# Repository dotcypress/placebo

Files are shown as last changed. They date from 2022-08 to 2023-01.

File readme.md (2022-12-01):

# Placebo

Truly minimal STM32G0/STM32C0 proto board.

## Features

* Breadboard/Perfboard friendly
* Power line bypass capacitors
* Reset circuit
* [`Tag-Connect TC2030-CTX-NL`](https://www.tag-connect.com/product/tc2030-ctx-nl-stdc14-for-use-with-stm32-processors-with-stlink-v3) programming connector
* Optional battery connector with LDO
* Optional configurable LED

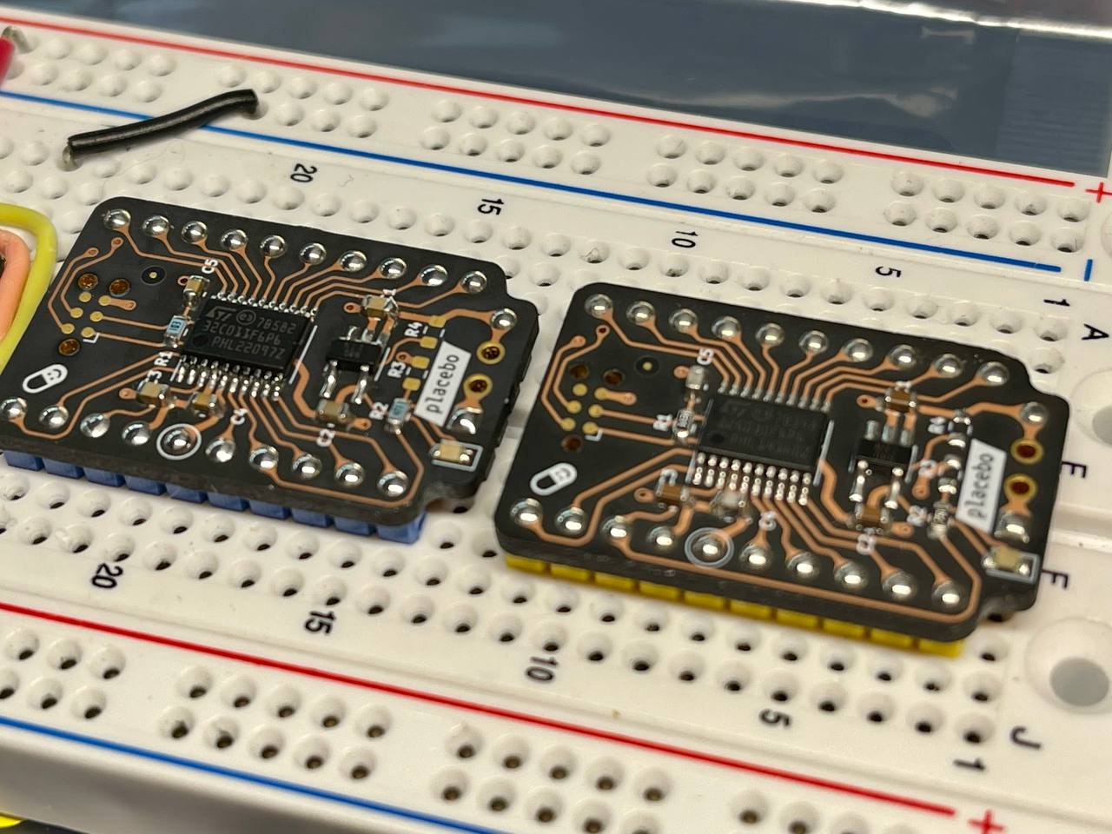
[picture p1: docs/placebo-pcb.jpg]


## Pinout

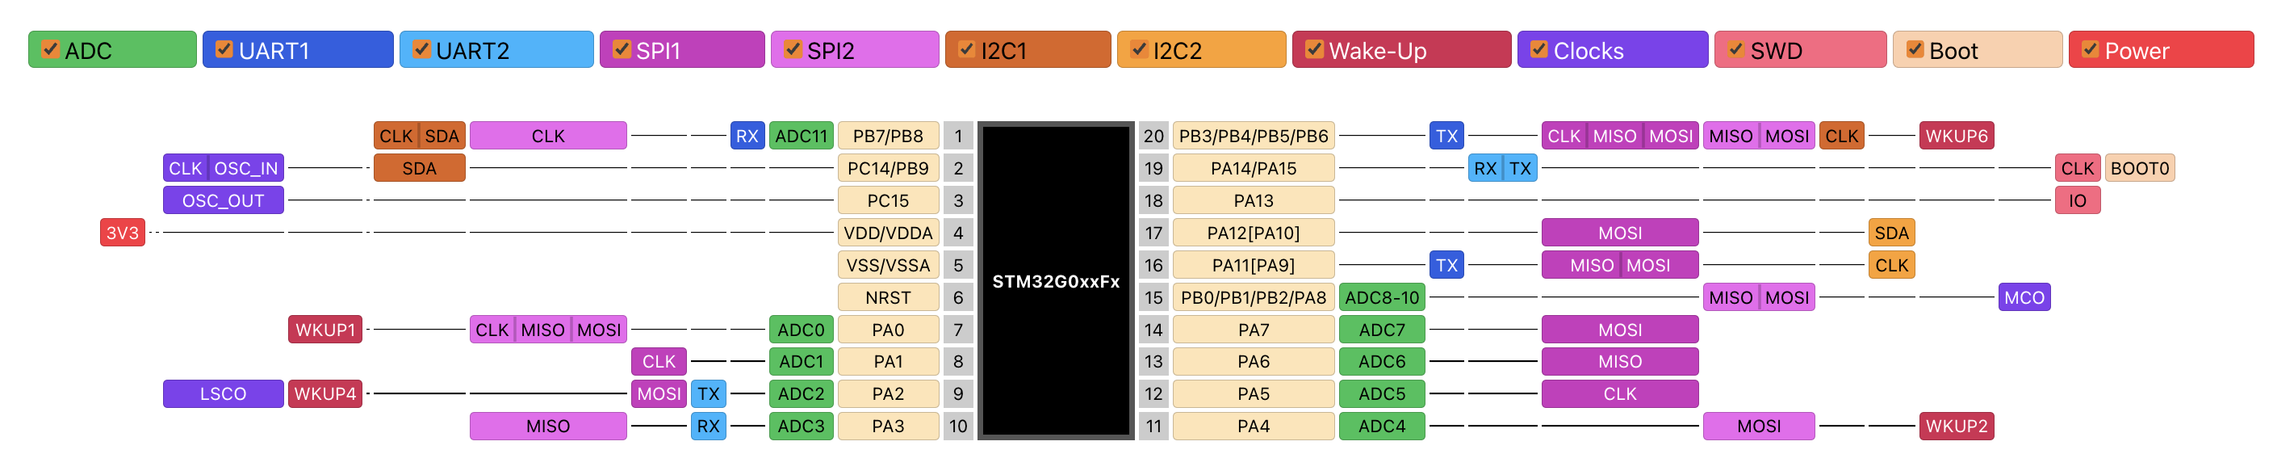
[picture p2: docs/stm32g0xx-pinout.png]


## Rust firmware

1. Install rustup by following the instructions at https://rustup.rs
2. Install Cortex-M0, M0+, and M1 (ARMv6-M architecture) target: `rustup target add thumbv6m-none-eabi`
3. Install LLVM tools: `rustup component add llvm-tools-preview`
4. Install cargo-binutils: `cargo install cargo-binutils` (Note: on some Linux distros (e.g. Ubuntu) you may need to install the packages build-essential, gcc-arm-none-eabi, libssl-dev and pkg-config prior to installing cargo-binutils.)
5. Install cargo-generate: `cargo install cargo-generate`
6. Generate project: `cargo generate --git https://github.com/dotcypress/placebo-template.git`
7. Build firmware: `cargo build --release`
8. Flash microcontroller: `cargo run --release`

## Resources

- [Order PCB on Oshpark](https://oshpark.com/shared_projects/tT7z3ldx)
- [Schematics](docs/placebo.pdf)
- [Gerber files](docs/placebo.zip)
- [BOM](docs/placebo.csv)
- [Interactive BOM](https://htmlpreview.github.io/?https://github.com/dotcypress/placebo/blob/main/docs/ibom.html)

## License

Licensed under either of

- Apache License, Version 2.0 ([LICENSE-APACHE](LICENSE-APACHE) or
  http://www.apache.org/licenses/LICENSE-2.0)
- MIT license ([LICENSE-MIT](LICENSE-MIT) or http://opensource.org/licenses/MIT)

at your option.

### Contribution

Unless you explicitly state otherwise, any contribution intentionally submitted
for inclusion in the work by you, as defined in the Apache-2.0 license, shall be
dual licensed as above, without any additional terms or conditions.

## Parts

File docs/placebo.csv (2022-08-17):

Designator | Comment | Footprint | Mouser Link
U1 | AP7370-33W5 | SOT-23-5 | https://www.mouser.com/c/?q=AP7370-33W5-7
U2 | STM32G030F6P6TR | TSSOP-20 | https://www.mouser.com/c/?q=STM32G030F6P6TR
D1 | LED | 0603 | https://www.mouser.com/c/?q=SML-D12W8WT86A
R1 | 10K | 0603 | https://www.mouser.com/c/?q=CRT0603-FZ-1002ELF
R2, R4 | 330R | 0603 | https://www.mouser.com/c/?q=CRT0603-FY-3300ELF
C3, C5 | 100nF | 0603 | https://www.mouser.com/c/?q=C0603C104J4RAC
C1, C2, C4 | 10uF | 0603 | https://www.mouser.com/c/?q=CL10A106MA8NRNC

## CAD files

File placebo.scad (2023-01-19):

module PlaceboCutout(height=1.6) {
  translate([-10.76, -16.6, -height/2])
    hull()
    linear_extrude(height=height, convexity=8)
    import(file="placebo.svg");
}

module PlaceboPCB(pin_height=10, pin_offset=2) {
  PlaceboCutout();

  translate([-0.1, 1.1, 0])
    cube([18.4, 26, 1.6], center=true);
  translate([-0.1, -12.4, 0])
    cube([14, 4, 1.6], center=true);

  for (i=[0:9]) {
    rotate([0, 0, 90]) {
      translate([i*2.54 - 10.2, 7.8, -pin_offset])
        cylinder(d=1.4, h=pin_height, center=true);
      translate([i*2.54 - 10.2, -7.5, -pin_offset])
        cylinder(d=1.4, h=pin_height, center=true);
    }
  }

  for (i=[-1:2]) {
    translate([i*2.54, -12.6, -pin_offset])
      cylinder(d=1.4, h=pin_height, center=true);
  }

  *translate([0, 11.8, 0.6])
    cube([7, 4, 0.6], center=true);
}

module Printer(d=7) {
  cr=3;
  h=3;
  w=64;
  l=50;

  difference() {
    union() {
      hull() {
        translate([w/2-cr,d,0]) cylinder(r=cr, h=h, center=true);
        translate([w/2-cr,l/2-cr,0]) cylinder(r=cr, h=h, center=true);
        translate([-w/2+cr,l/2-cr,0]) cylinder(r=cr, h=h, center=true);
        translate([-w/2+cr,0,0]) cylinder(r=cr, h=h, center=true);
      }
      hull() {
        translate([w/2-cr,-l/2+cr,0]) cylinder(r=cr, h=h, center=true);
        translate([w/2-cr,-d,0]) cylinder(r=cr, h=h, center=true);
        translate([-w/2+cr,0,0]) cylinder(r=cr, h=h, center=true);
        translate([-w/2+cr,-l/2+cr,0]) cylinder(r=cr, h=h, center=true);
      }
    }
    rotate([0,0,90])
      translate([0,-3,h/2-0.79])
      PlaceboCutout();
    rotate([0,0,90])
      translate([0,-3,h/2-0.79])
      scale([0.85,0.9,10]) 
      PlaceboCutout();
  }
}

$fn=128;

// projection(cut=true) translate([0,0,1])
Printer();

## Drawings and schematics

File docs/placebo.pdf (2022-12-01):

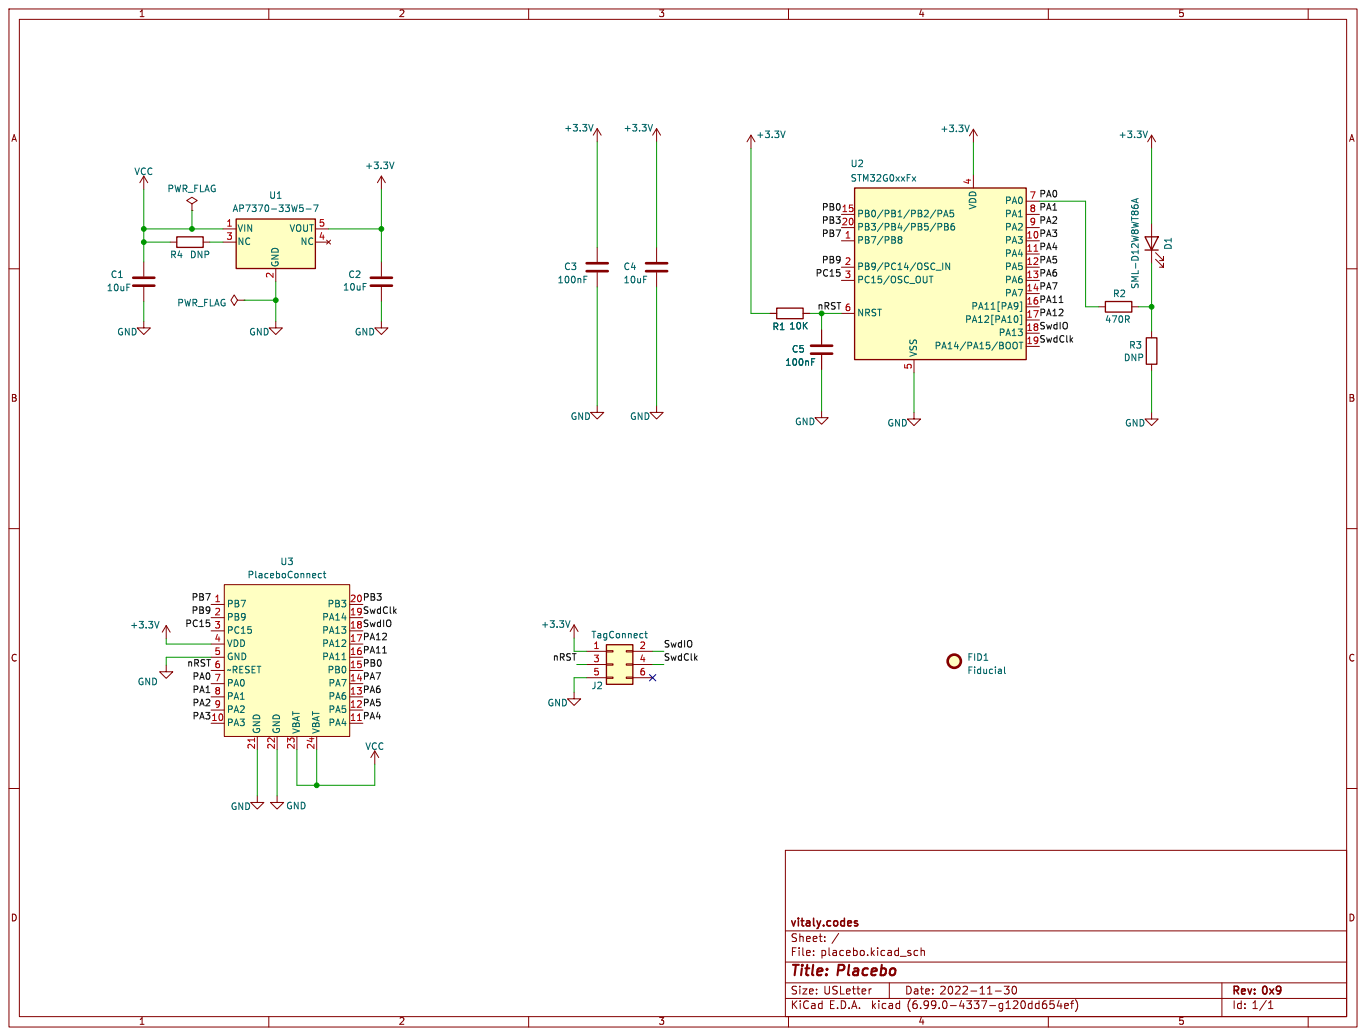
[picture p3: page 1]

2 NC 3 NC 4 VOUT 5 U1 AP7370-33W5-7 GND

File: placebo.kicad_sch Sheet: / vitaly.codes

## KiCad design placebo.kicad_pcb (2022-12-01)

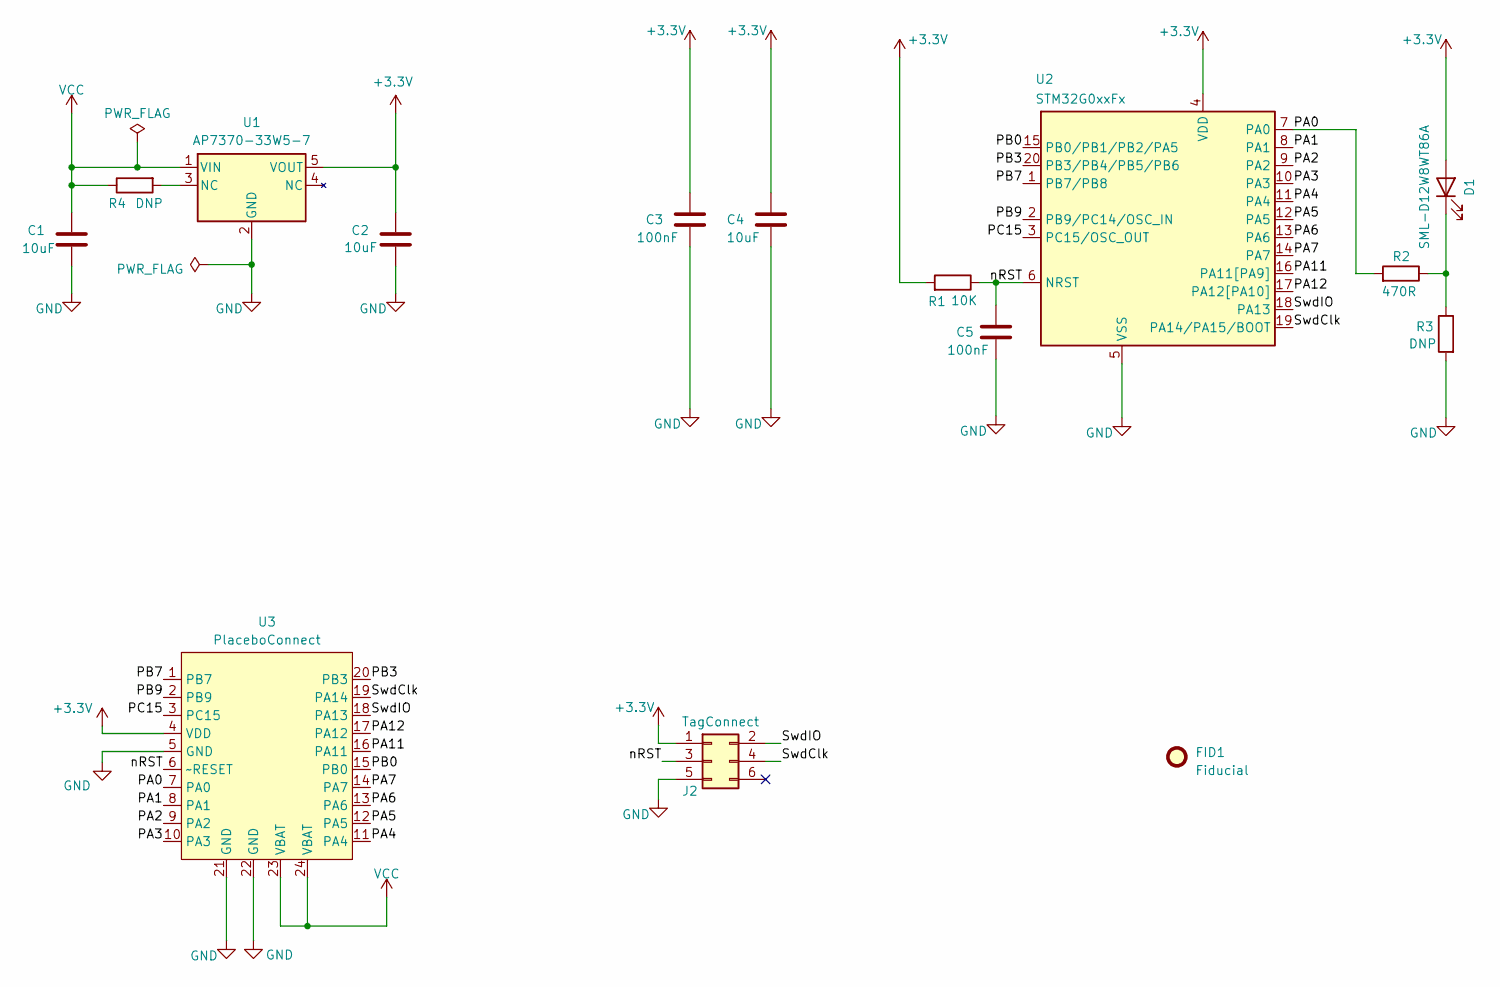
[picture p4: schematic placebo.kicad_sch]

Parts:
C1, C2, C4: 10uF; C_0603_1608Metric
C3, C5: 100nF; C_0603_1608Metric
D1: SML-D12W8WT86A; LED_0603_1608Metric
FID1: Fiducial; Fiducial_0.5mm_Mask1.5mm
J2: TagConnect; Tag-Connect_TC2030-IDC-NL_2x03_P1.27mm_Vertical
R1: 10K; R_0603_1608Metric
R2: 470R; R_0603_1608Metric
R3, R4: DNP; R_0603_1608Metric
U1: AP7370-33W5-7; TSOT-23-5_HandSoldering
U2: STM32G0xxFx; TSSOP-20_4.4x6.5mm_P0.65mm
U3: PlaceboConnect; PlaceboConnect_Cutout

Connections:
+3V3: C2.1, C3.1, C4.1, D1.2 (A), J2.1, R1.2, U1.5 (VOUT), U2.4 (VDD), U3.4 (VDD)
/PA0: R2.2, U2.7 (PA0), U3.7 (PA0)
/PA1: U2.8 (PA1), U3.8 (PA1)
/PA2: U2.9 (PA2), U3.9 (PA2)
/PA3: U2.10 (PA3), U3.10 (PA3)
/PA4: U2.11 (PA4), U3.11 (PA4)
/PA5: U2.12 (PA5), U3.12 (PA5)
/PA6: U2.13 (PA6), U3.13 (PA6)
/PA7: U2.14 (PA7), U3.14 (PA7)
/PA11: U2.16 (PA11[PA9]), U3.16 (PA11)
/PA12: U2.17 (PA12[PA10]), U3.17 (PA12)
/PB0: U2.15 (PB0/PB1/PB2/PA5), U3.15 (PB0)
/PB3: U2.20 (PB3/PB4/PB5/PB6), U3.20 (PB3)
/PB7: U2.1 (PB7/PB8), U3.1 (PB7)
/PB9: U2.2 (PB9/PC14/OSC_IN), U3.2 (PB9)
/PC15: U2.3 (PC15/OSC_OUT), U3.3 (PC15)
/SwdClk: J2.4, U2.19 (PA14/PA15/BOOT), U3.19 (PA14)
/SwdIO: J2.2, U2.18 (PA13), U3.18 (PA13)
/nRST: C5.1, J2.3, R1.1, U2.6 (NRST), U3.6 (~RESET)
GND: C1.2, C2.2, C3.2, C4.2, C5.2, J2.5, R3.2, U1.2 (GND), U2.5 (VSS), U3.5 (GND), U3.21 (GND), U3.22 (GND)
unnamed: D1.1 (K), R2.1, R3.1
unnamed: R4.2, U1.3 (NC)
VCC: C1.1, R4.1, U1.1 (VIN), U3.23 (VBAT), U3.24 (VBAT)

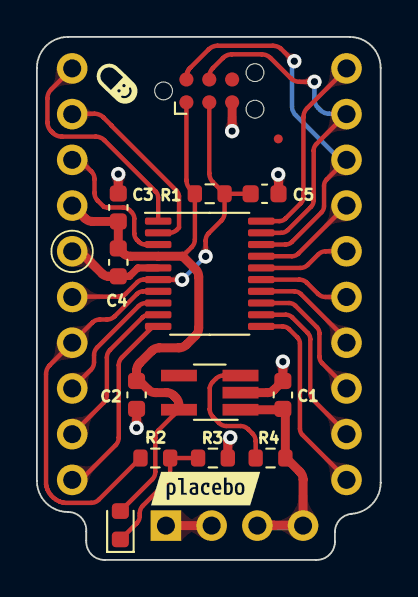
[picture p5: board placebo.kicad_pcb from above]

Board: 2 copper layers, 19.1 x 29.1 mm, 17 parts (0 on the bottom side), 23 nets.

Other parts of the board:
LOGO1: LOGO
kibuzzard-631021FD: G***; kibuzzard-631021FD

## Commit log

2021-07-22 rev 1
    [placebo.csv, placebo.kicad_pcb, placebo.kicad_sch]
2021-07-23 update docs
    [placebo.kicad_pcb]
2021-08-26 rev 2
    [placebo.kicad_pcb]
2021-12-26 rev 0x3
    [placebo.kicad_pcb, placebo.kicad_sch]
2022-07-19 rev 0x4
    [placebo.kicad_pcb, placebo.kicad_sch]
2022-08-14 rev. 0x6
    [placebo.csv, placebo.kicad_pcb, placebo.kicad_sch]
2022-08-19 add cad files
    [placebo.kicad_pcb, placebo.scad]
2022-09-04 rev. 0x8
    [placebo.kicad_pcb, placebo.kicad_sch, placebo.scad]
2022-09-17 panel rev. 0x8
    [placebo.kicad_pcb]
2022-09-17 update BOM
    [placebo.kicad_pcb, placebo.kicad_sch]
2023-01-19 update photo
    [placebo.scad]
